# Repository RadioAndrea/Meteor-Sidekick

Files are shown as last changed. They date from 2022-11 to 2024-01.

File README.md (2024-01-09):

# Meteor-Sidekick
Slide out keyboard for modern smartphones

Uses Nice!Nano as a microcontroller and the first implementation is sized to a Pixel 7 Pro

Current implementation is with the Kailh Scissor switches as they are very thin and available unlike the ultramecs 6c switches.

If you know of a way to get thinner mechanical switches, like the Ultramecs, at a reasonable price (not $150 a board), please raise an issue in this repo.

# Project Status
## November 2022
Boards that were created were milled with the wrong size of drill bit due to board fab error.
Fabricator remade boards to rectify this.

## January 2023
New boards arrived and components are still being collected.

## Jul 2023
Solder paste stencil arrived and reflow oven was obtained.
Soldering of transistors will happen by paste and reflow, while switches will be done entirely by hand.

## Jan 2024
Board has been produced and now soldered thanks to my steady handed assistant.

# Images
## Real Photographs
### SMD Soldering
SMD parts reflow soldered

### Adding Switches and Caps
Swithches installed, caps being added
### Praise the manufacturing tolerances
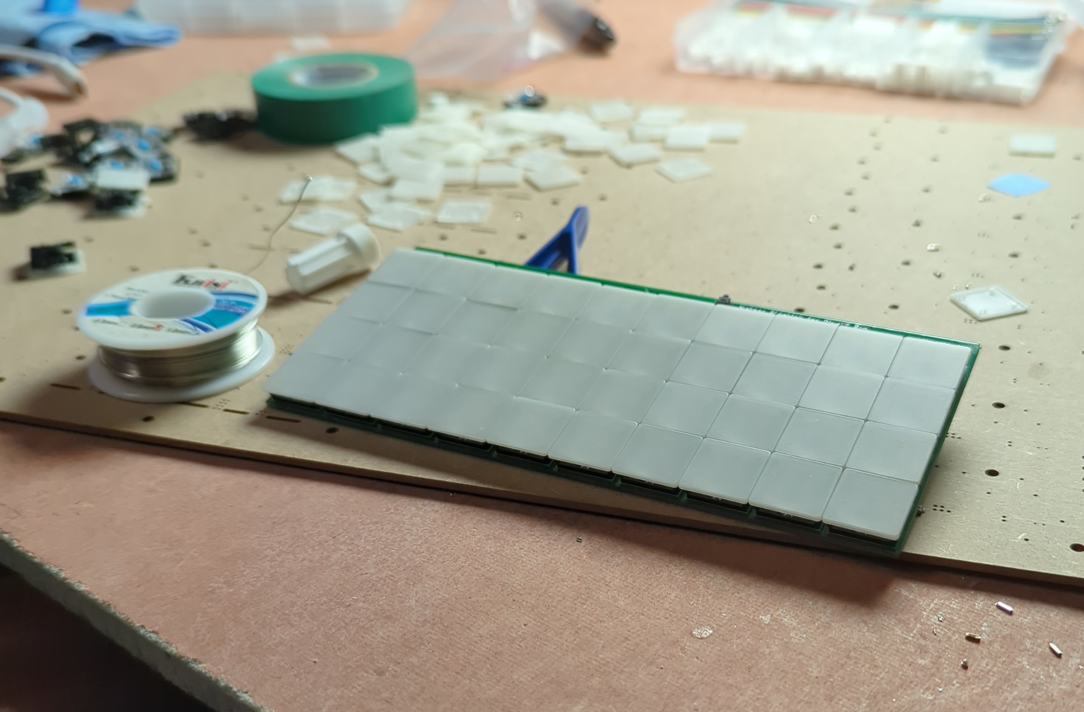
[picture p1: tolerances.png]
Only one keyswitch was out of tolerence


## 2D Drawing
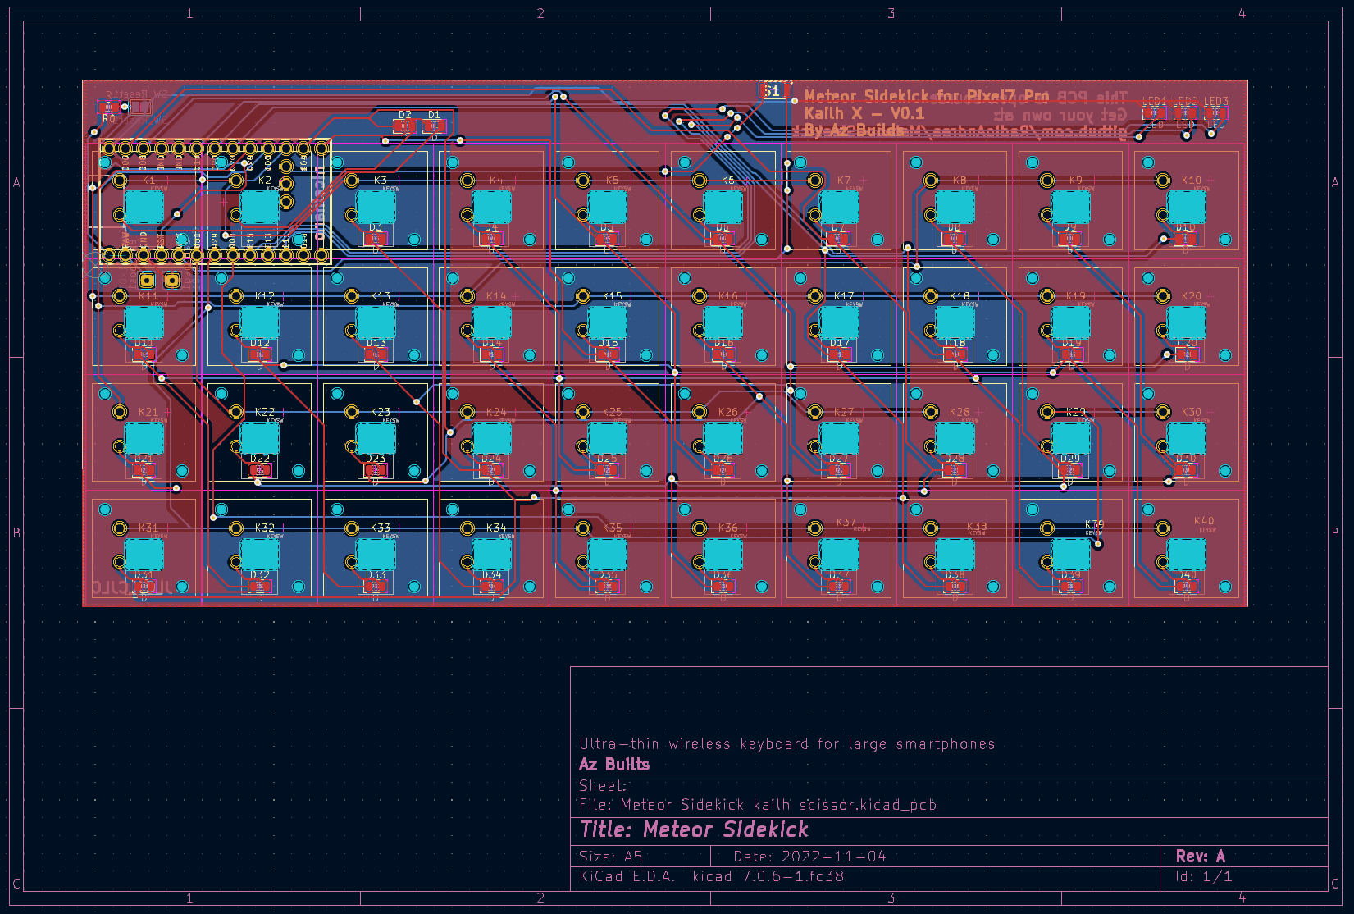
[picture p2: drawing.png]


## 3D Render
### Front

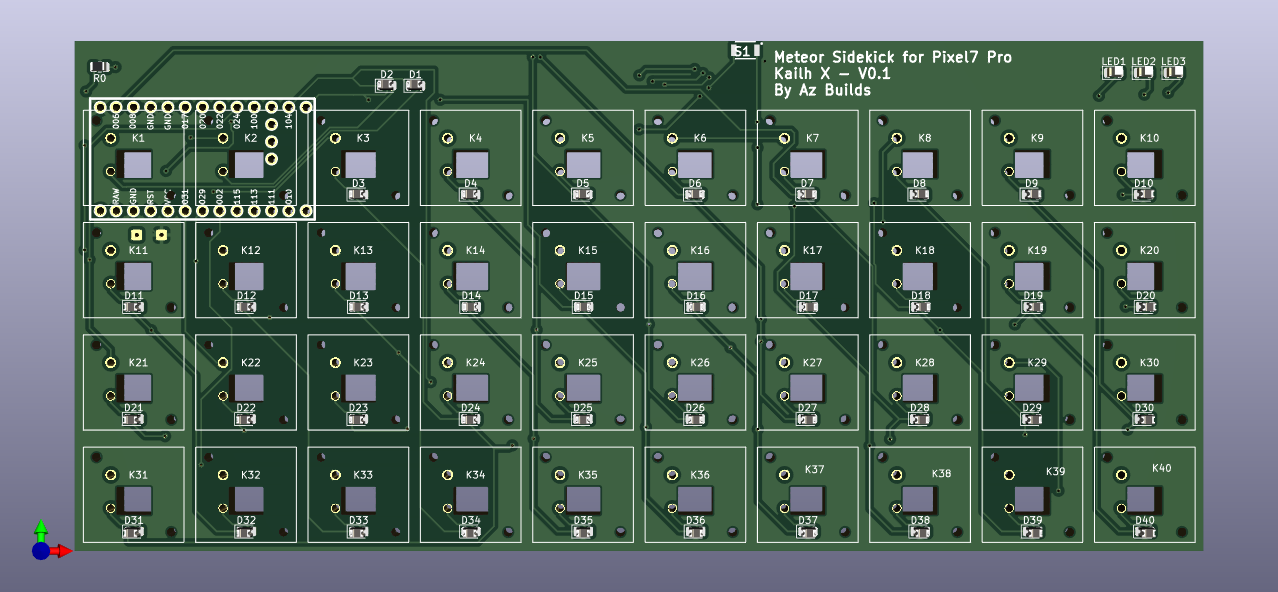
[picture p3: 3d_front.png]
Front of keyboard

### Back
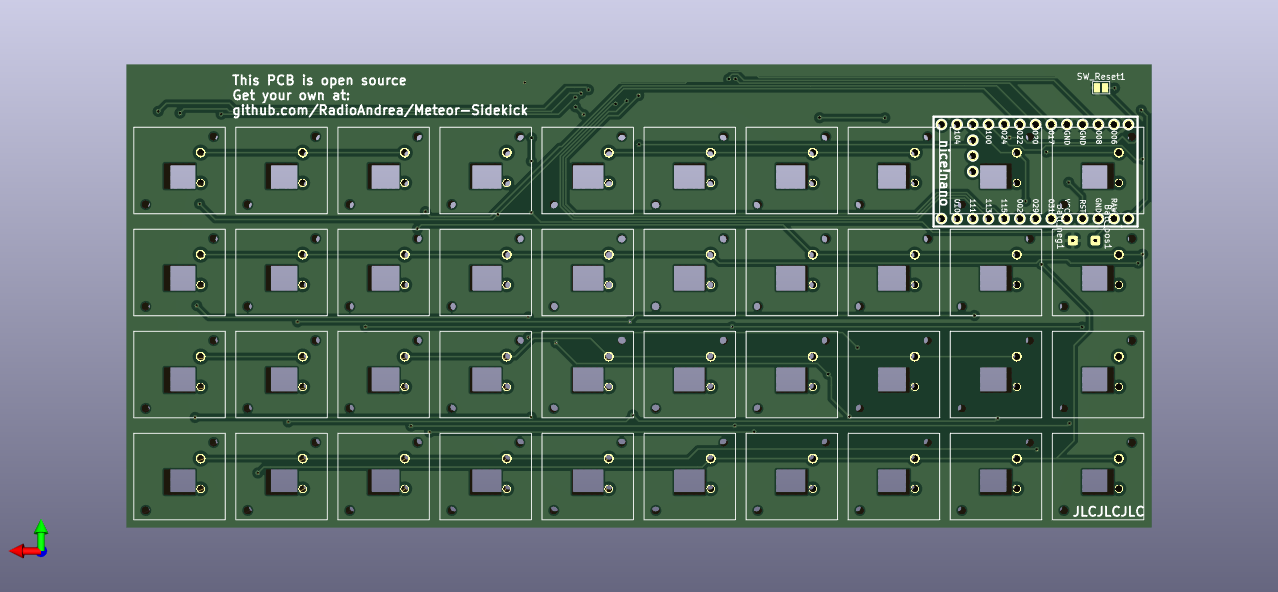
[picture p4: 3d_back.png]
Back of keyboard


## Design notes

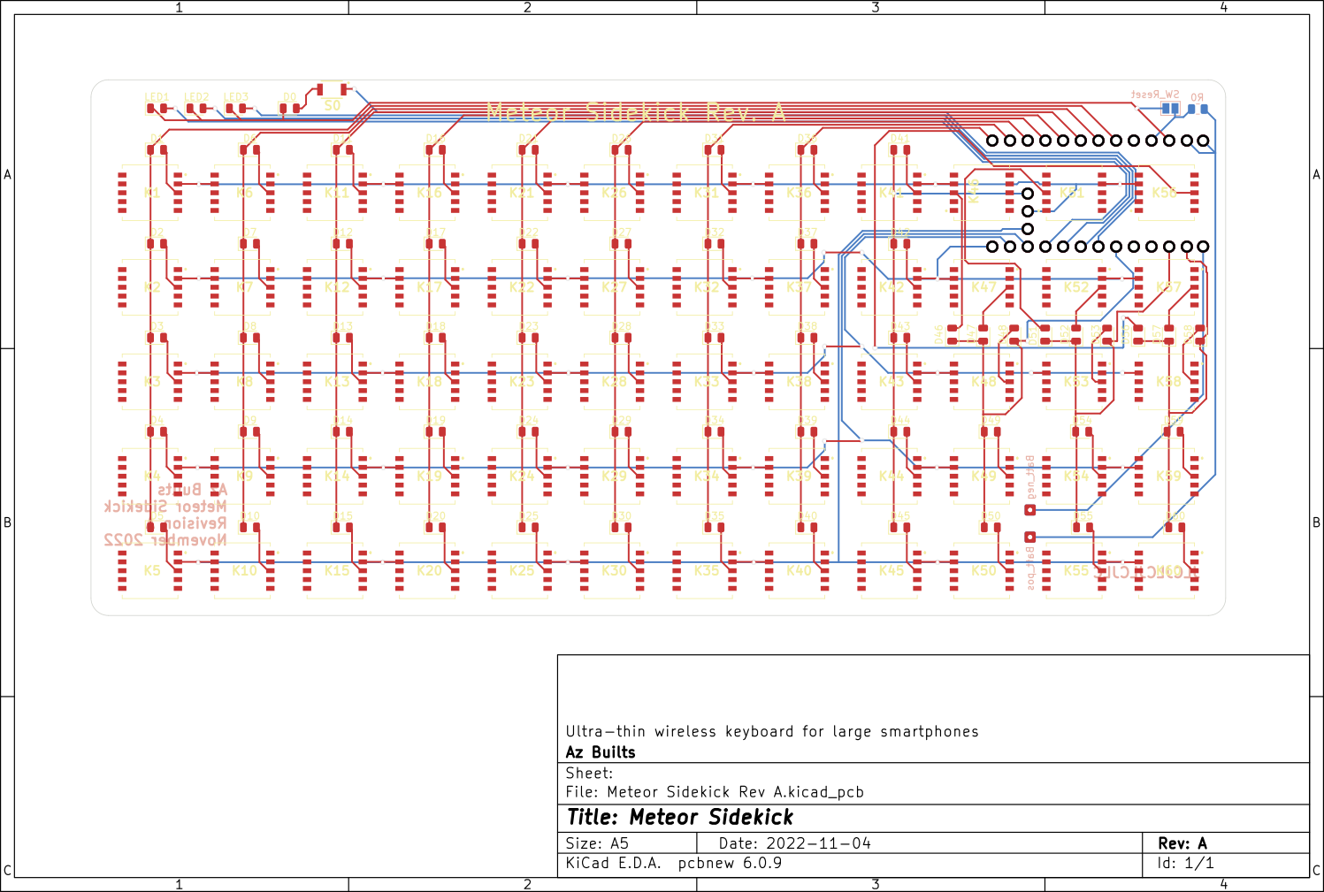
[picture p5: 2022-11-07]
ultramec-6/Meteor Sidekick Rev A.png

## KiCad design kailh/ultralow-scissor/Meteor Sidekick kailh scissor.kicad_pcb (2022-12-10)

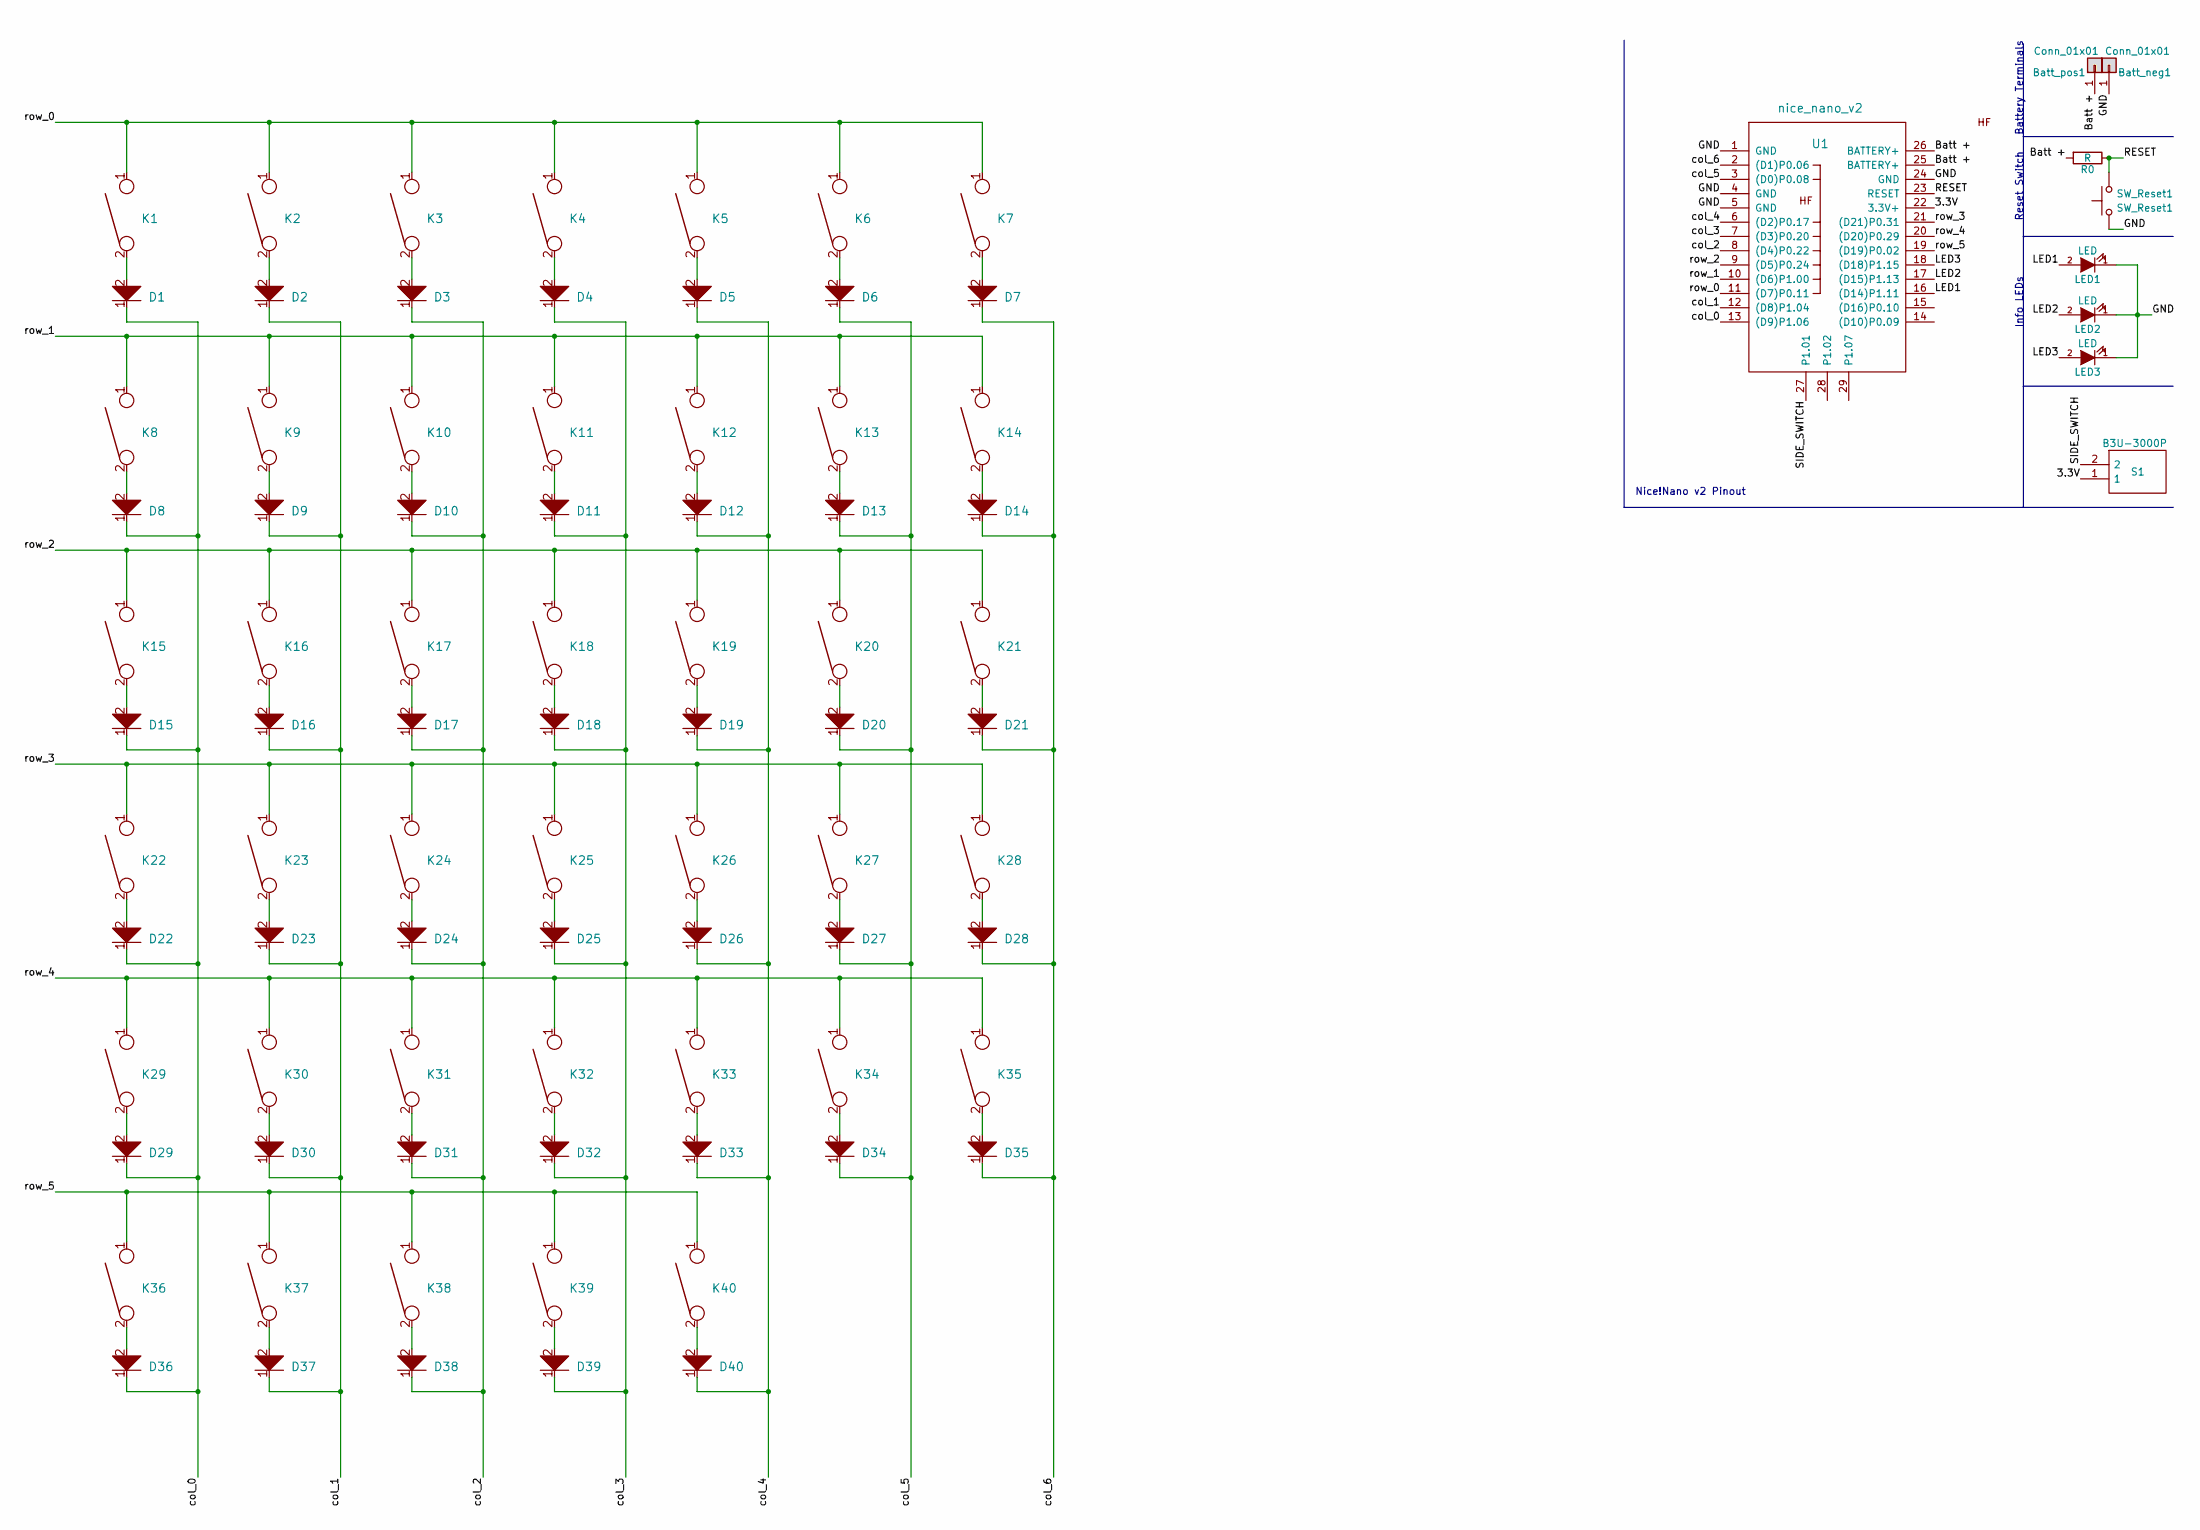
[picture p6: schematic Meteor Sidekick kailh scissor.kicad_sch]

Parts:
Batt_neg1: Conn_01x01; SolderWire-0.1sqmm_1x01_D0.4mm_OD1mm
Batt_pos1: Conn_01x01; SolderWire-0.1sqmm_1x01_D0.4mm_OD1mm
D1, D2, D3, D4, D5, D6, D7, D8, D9, D10, D11, D12, D13, D14, D15, D16, D17, D18, D19, D20, D21, D22, D23, D24, D25, D26, D27, D28, D29, D30, D31, D32, D33, D34, D35, D36, D37, D38, D39, D40: D; D_0805_2012Metric
K1, K2, K3, K4, K5, K6, K7, K8, K9, K10, K11, K12, K13, K14, K15, K16, K17, K18, K19, K20, K21, K22, K23, K24, K25, K26, K27, K28, K29, K30, K31, K32, K33, K34, K35, K36, K37, K38, K39, K40: KEYSW; Kailh-PG1425-X-Switch
LED1, LED2, LED3: LED; LED_0805_2012Metric
R0: R; R_0805_2012Metric
S1: B3U-3000P; B3U-1000P; Mouser Part Number 653-B3U-3000P
SW_Reset1: SW_Reset1; SolderJumper-2_P1.3mm_Open_Pad1.0x1.5mm
U1: nice_nano_v2

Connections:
/3.3V: S1.1, U1.22 (3.3V+)
/Batt +: Batt_pos1.1, R0.2, U1.25 (BATTERY+), U1.26 (BATTERY+)
/GND: Batt_neg1.1, LED1.1 (K), LED2.1 (K), LED3.1 (K), SW_Reset1.1, U1.1 (GND), U1.4 (GND), U1.5 (GND), U1.24 (GND)
/LED1: LED1.2 (A), U1.16 ((D14)P1.11)
/LED2: LED2.2 (A), U1.17 ((D15)P1.13)
/LED3: LED3.2 (A), U1.18 ((D18)P1.15)
/RESET: R0.1, SW_Reset1.2, U1.23 (RESET)
/SIDE_SWITCH: S1.2, U1.27 (P1.01)
/col_0: D1.1, D8.1, D15.1, D22.1, D29.1, D36.1, U1.13 ((D9)P1.06)
/col_1: D2.1, D9.1, D16.1, D23.1, D30.1, D37.1, U1.12 ((D8)P1.04)
/col_2: D3.1, D10.1, D17.1, D24.1, D31.1, D38.1, U1.8 ((D4)P0.22)
/col_3: D4.1, D11.1, D18.1, D25.1, D32.1, D39.1, U1.7 ((D3)P0.20)
/col_4: D5.1, D12.1, D19.1, D26.1, D33.1, D40.1, U1.6 ((D2)P0.17)
/col_5: D6.1, D13.1, D20.1, D27.1, D34.1, U1.3 ((D0)P0.08)
/col_6: D7.1, D14.1, D21.1, D28.1, D35.1, U1.2 ((D1)P0.06)
/row_0: K1.1, K2.1, K3.1, K4.1, K5.1, K6.1, K7.1, U1.11 ((D7)P0.11)
/row_1: K8.1, K9.1, K10.1, K11.1, K12.1, K13.1, K14.1, U1.10 ((D6)P1.00)
/row_2: K15.1, K16.1, K17.1, K18.1, K19.1, K20.1, K21.1, U1.9 ((D5)P0.24)
/row_3: K22.1, K23.1, K24.1, K25.1, K26.1, K27.1, K28.1, U1.21 ((D21)P0.31)
/row_4: K29.1, K30.1, K31.1, K32.1, K33.1, K34.1, K35.1, U1.20 ((D20)P0.29)
/row_5: K36.1, K37.1, K38.1, K39.1, K40.1, U1.19 ((D19)P0.02)
unnamed: D1.2, K1.2
unnamed: D2.2, K2.2
unnamed: D3.2, K3.2
unnamed: D4.2, K4.2
unnamed: D5.2, K5.2
unnamed: D6.2, K6.2
unnamed: D7.2, K7.2
unnamed: D8.2, K8.2
unnamed: D9.2, K9.2
unnamed: D10.2, K10.2
unnamed: D11.2, K11.2
unnamed: D12.2, K12.2
unnamed: D13.2, K13.2
unnamed: D14.2, K14.2
unnamed: D15.2, K15.2
unnamed: D16.2, K16.2
unnamed: D17.2, K17.2
unnamed: D18.2, K18.2
unnamed: D19.2, K19.2
unnamed: D20.2, K20.2
unnamed: D21.2, K21.2
unnamed: D22.2, K22.2
unnamed: D23.2, K23.2
unnamed: D24.2, K24.2
unnamed: D25.2, K25.2
unnamed: D26.2, K26.2
unnamed: D27.2, K27.2
unnamed: D28.2, K28.2
unnamed: D29.2, K29.2
unnamed: D30.2, K30.2
unnamed: D31.2, K31.2
unnamed: D32.2, K32.2
unnamed: D33.2, K33.2
unnamed: D34.2, K34.2
unnamed: D35.2, K35.2
unnamed: D36.2, K36.2
unnamed: D37.2, K37.2
unnamed: D38.2, K38.2
unnamed: D39.2, K39.2
unnamed: D40.2, K40.2

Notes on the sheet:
Nice!Nano v2 Pinout
Battery Terminals
Reset Switch
Info LEDs

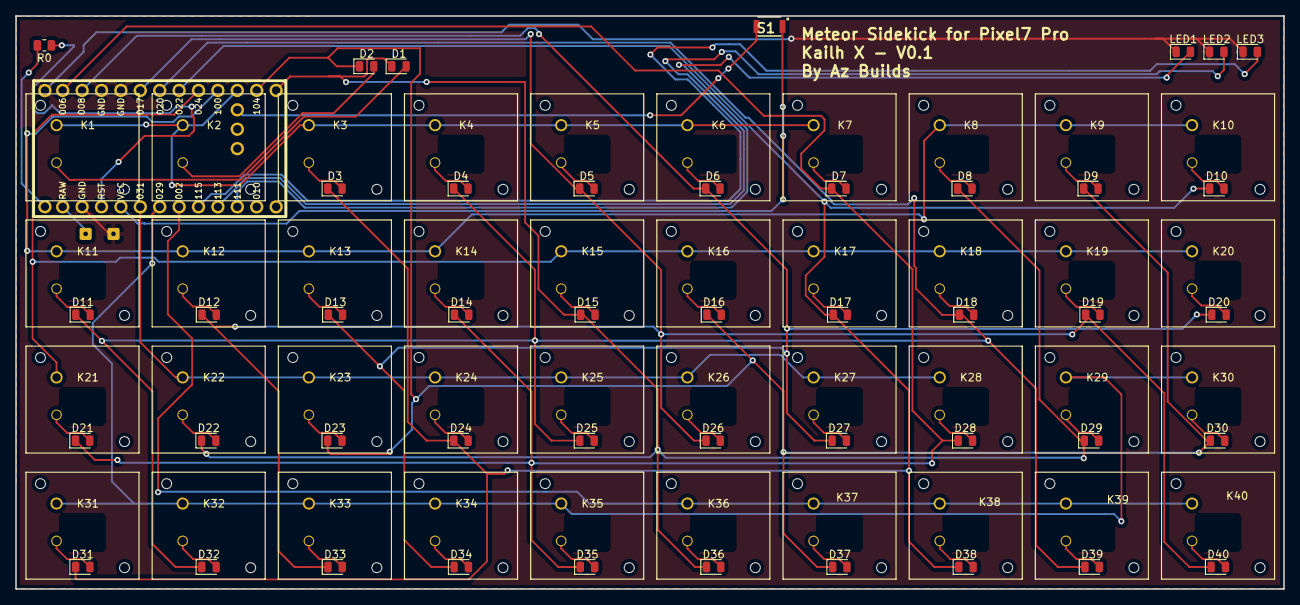
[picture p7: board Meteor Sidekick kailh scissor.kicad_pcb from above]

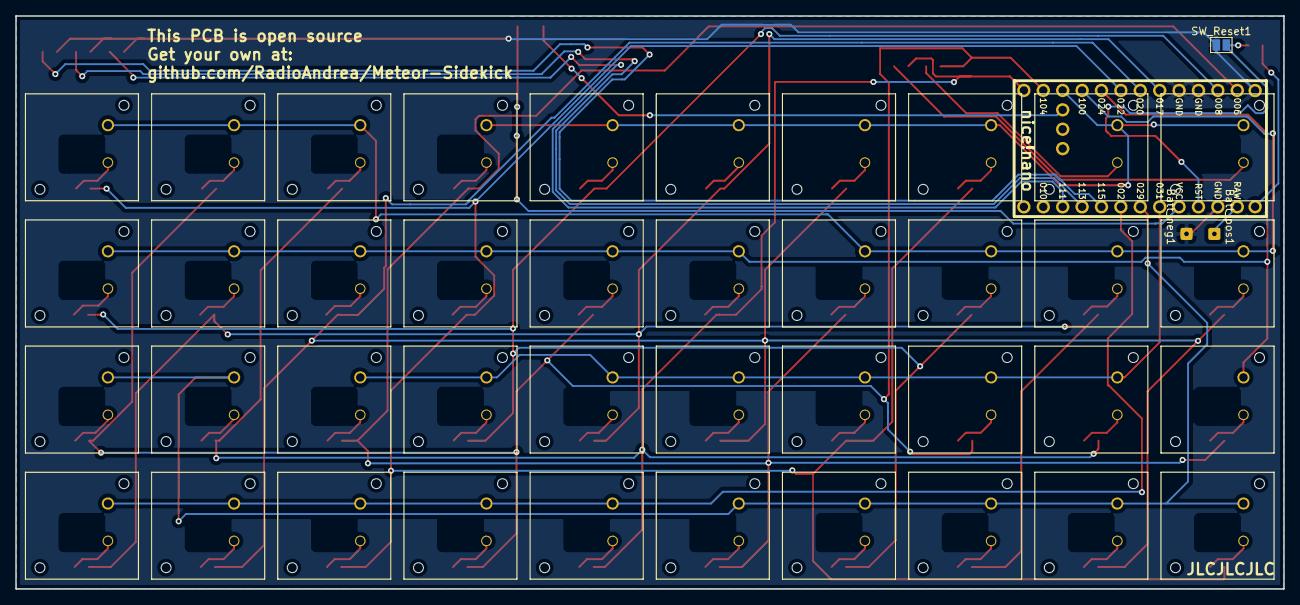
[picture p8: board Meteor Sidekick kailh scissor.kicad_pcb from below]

Board: 2 copper layers, 166.0 x 75.0 mm, 89 parts (4 on the bottom side), 61 nets.

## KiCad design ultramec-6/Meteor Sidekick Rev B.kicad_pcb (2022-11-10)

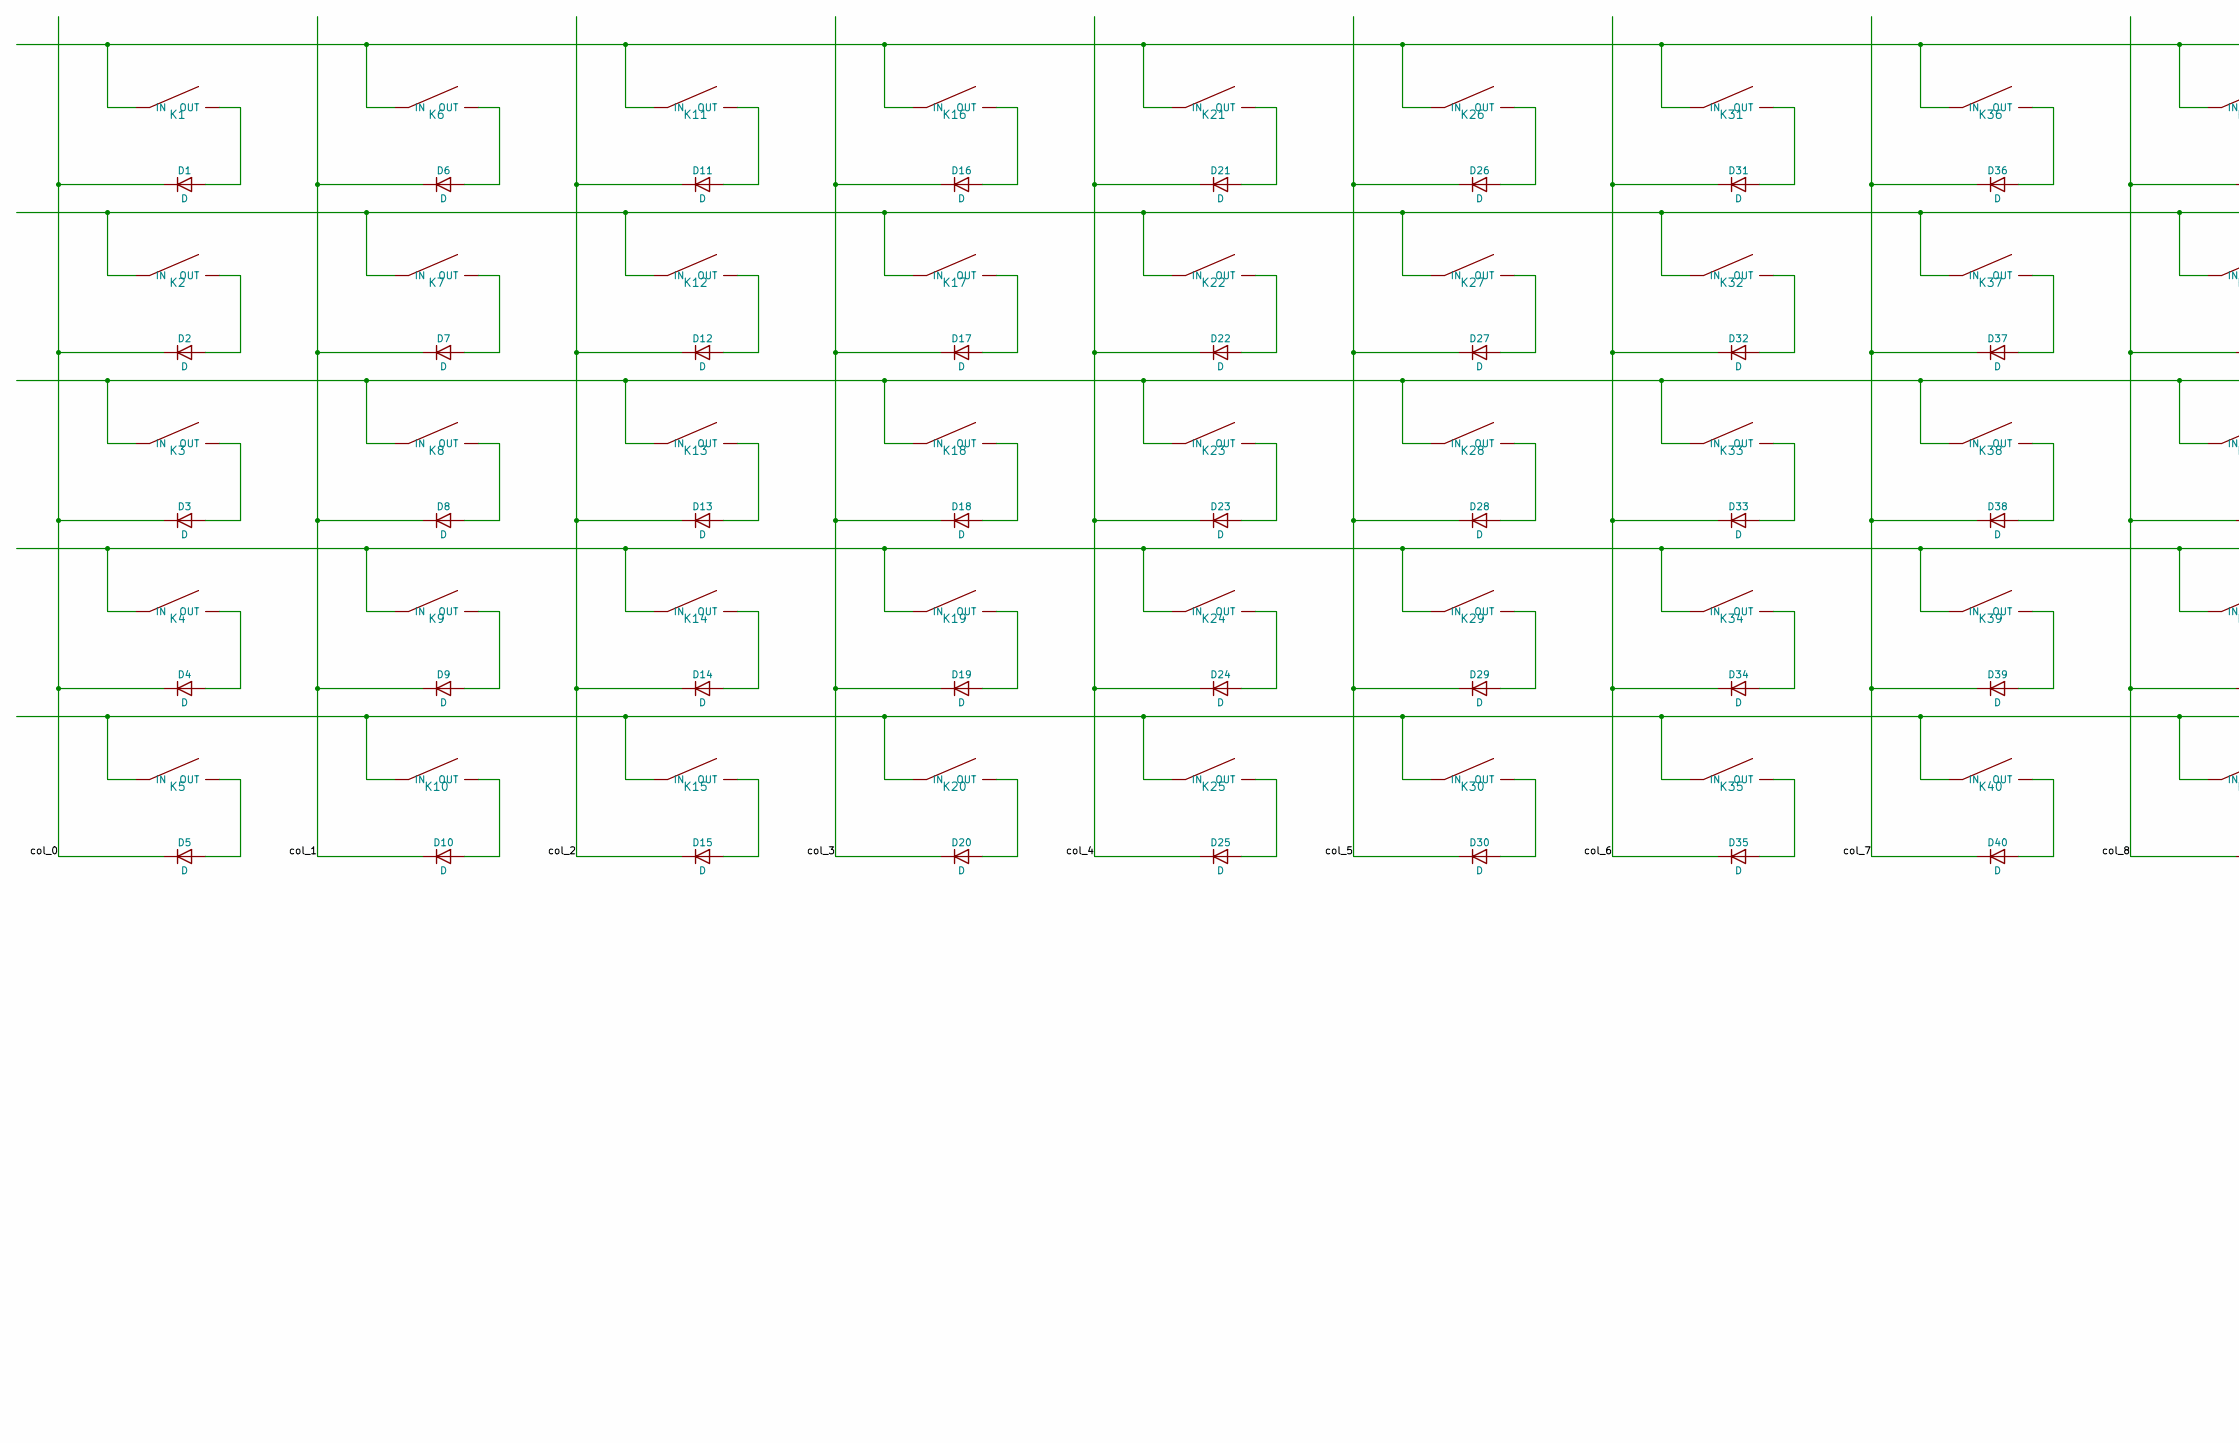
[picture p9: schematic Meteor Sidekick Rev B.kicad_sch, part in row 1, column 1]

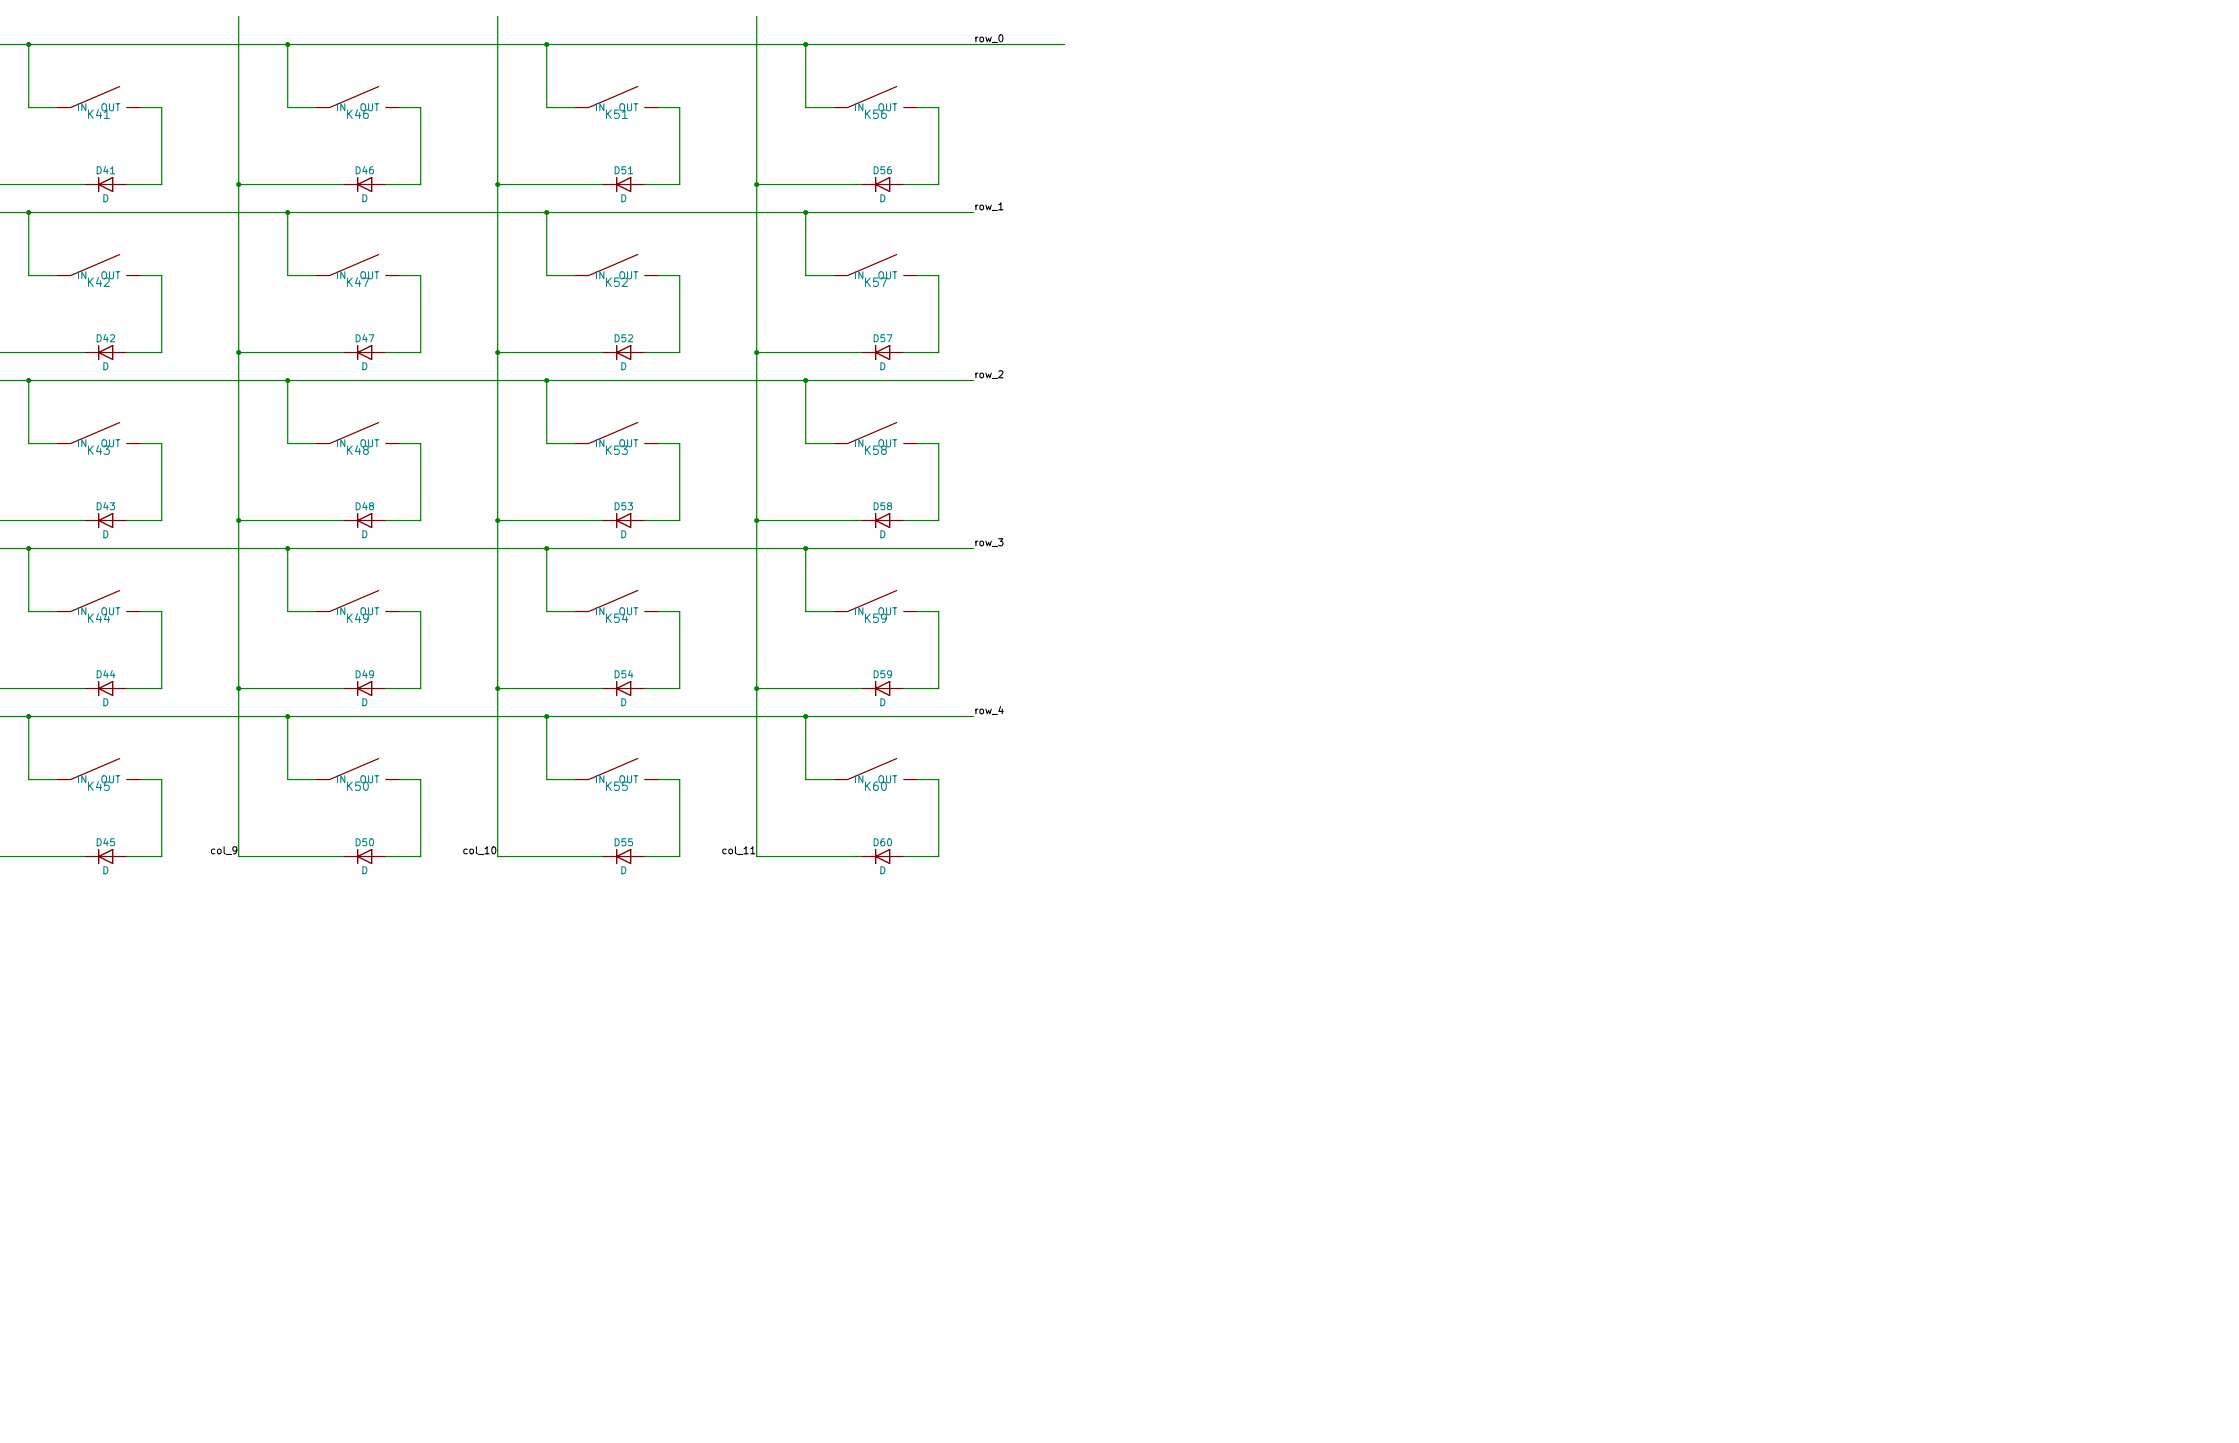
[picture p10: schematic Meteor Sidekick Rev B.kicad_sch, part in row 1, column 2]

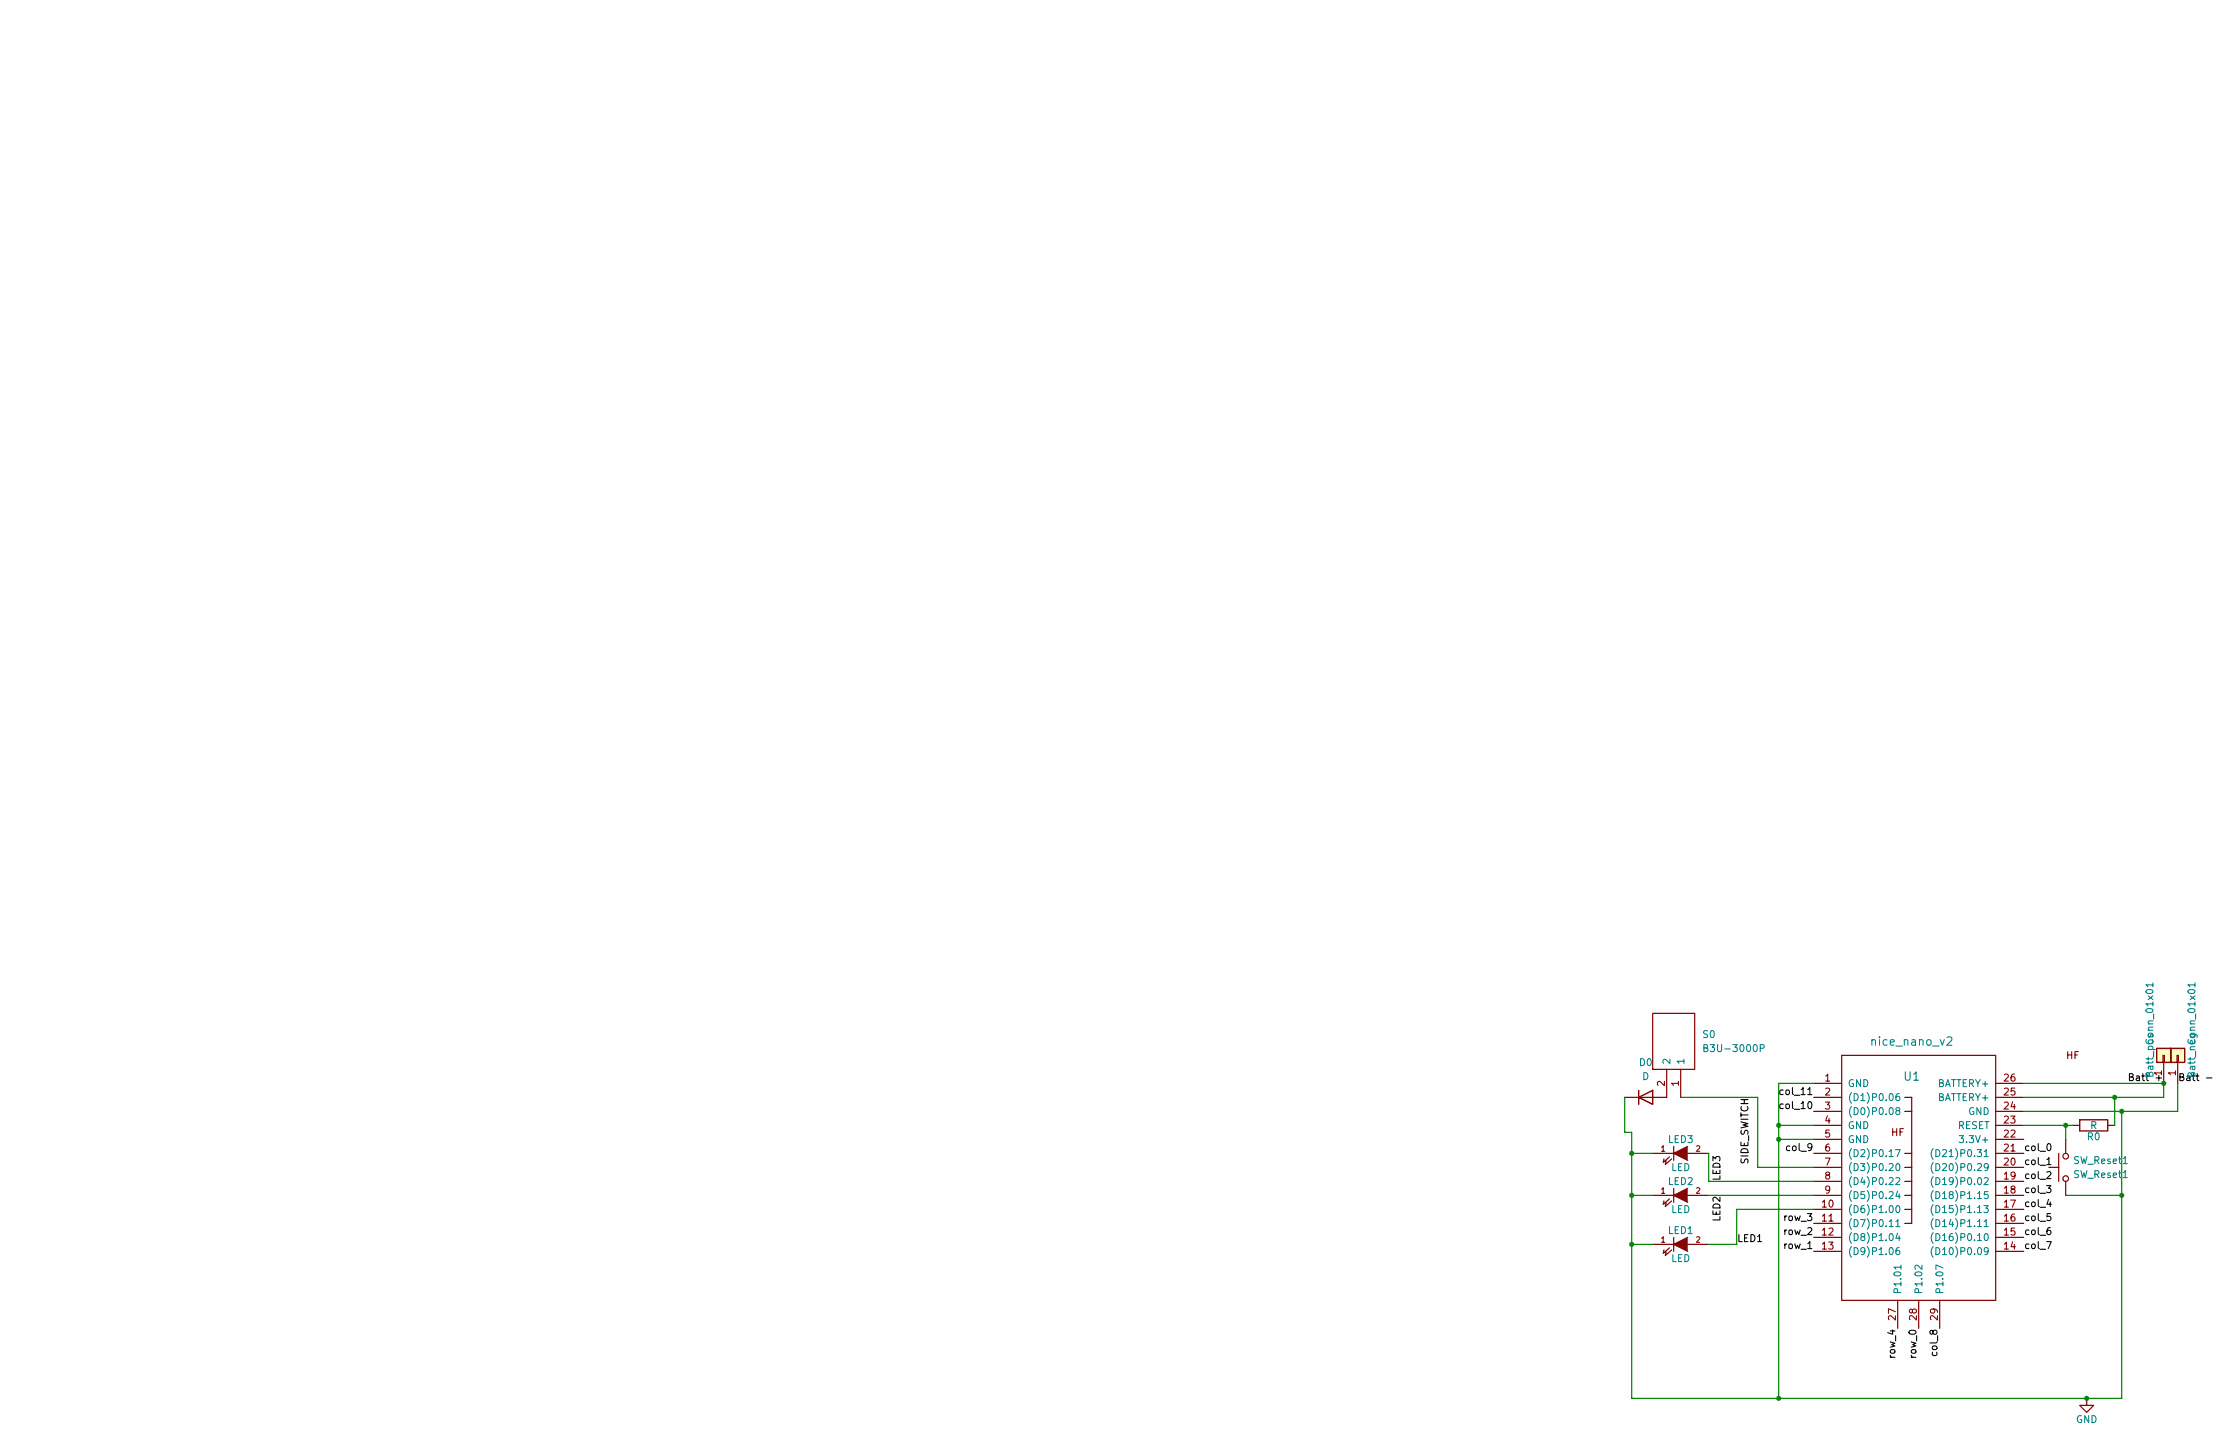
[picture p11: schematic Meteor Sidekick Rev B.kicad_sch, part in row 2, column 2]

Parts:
Batt_neg: Conn_01x01; SolderWire-0.1sqmm_1x01_D0.4mm_OD1mm
Batt_pos: Conn_01x01; SolderWire-0.1sqmm_1x01_D0.4mm_OD1mm
D0, D1, D2, D3, D4, D5, D6, D7, D8, D9, D10, D11, D12, D13, D14, D15, D16, D17, D18, D19, D20, D21, D22, D23, D24, D25, D26, D27, D28, D29, D30, D31, D32, D33, D34, D35, D36, D37, D38, D39, D40, D41, D42, D43, D44, D45, D46, D47, D48, D49, D50, D51, D52, D53, D54, D55, D56, D57, D58, D59, D60: D; D_0805_2012Metric
K1, K2, K3, K4, K5, K6, K7, K8, K9, K10, K11, K12, K13, K14, K15, K16, K17, K18, K19, K20, K21, K22, K23, K24, K25, K26, K27, K28, K29, K30, K31, K32, K33, K34, K35, K36, K37, K38, K39, K40, K41, K42, K43, K44, K45, K46, K47, K48, K49, K50, K51, K52, K53, K54, K55, K56, K57, K58, K59, K60: KEYSW_10; 6CJ1N0PR
LED1, LED2, LED3: LED; LED_0805_2012Metric
R0: R; R_0805_2012Metric
S0: B3U-3000P; B3U-1000P; Mouser Part Number 653-B3U-3000P
SW_Reset1: SW_Reset1; SolderJumper-2_P1.3mm_Open_Pad1.0x1.5mm
U1: nice_nano_v2

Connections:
/Batt +: Batt_pos.1, R0.1, U1.25 (BATTERY+), U1.26 (BATTERY+)
/LED1: LED1.2 (A), U1.10 ((D6)P1.00)
/LED2: LED2.2 (A), U1.9 ((D5)P0.24)
/LED3: LED3.2 (A), U1.8 ((D4)P0.22)
/SIDE_SWITCH: S0.1, U1.7 ((D3)P0.20)
/col_0: D1.1 (K), D2.1 (K), D3.1 (K), D4.1 (K), D5.1 (K), U1.21 ((D21)P0.31)
/col_1: D6.1 (K), D7.1 (K), D8.1 (K), D9.1 (K), D10.1 (K), U1.20 ((D20)P0.29)
/col_2: D11.1 (K), D12.1 (K), D13.1 (K), D14.1 (K), D15.1 (K), U1.19 ((D19)P0.02)
/col_3: D16.1 (K), D17.1 (K), D18.1 (K), D19.1 (K), D20.1 (K), U1.18 ((D18)P1.15)
/col_4: D21.1 (K), D22.1 (K), D23.1 (K), D24.1 (K), D25.1 (K), U1.17 ((D15)P1.13)
/col_5: D26.1 (K), D27.1 (K), D28.1 (K), D29.1 (K), D30.1 (K), U1.16 ((D14)P1.11)
/col_6: D31.1 (K), D32.1 (K), D33.1 (K), D34.1 (K), D35.1 (K), U1.15 ((D16)P0.10)
/col_7: D36.1 (K), D37.1 (K), D38.1 (K), D39.1 (K), D40.1 (K), U1.14 ((D10)P0.09)
/col_8: D41.1 (K), D42.1 (K), D43.1 (K), D44.1 (K), D45.1 (K), U1.29 (P1.07)
/col_9: D46.1 (K), D47.1 (K), D48.1 (K), D49.1 (K), D50.1 (K), U1.6 ((D2)P0.17)
/col_10: D51.1 (K), D52.1 (K), D53.1 (K), D54.1 (K), D55.1 (K), U1.3 ((D0)P0.08)
/col_11: D56.1 (K), D57.1 (K), D58.1 (K), D59.1 (K), D60.1 (K), U1.2 ((D1)P0.06)
/row_0: K1.3 (IN), K1.4 (IN), K1.7 (IN), K1.8 (IN), K6.3 (IN), K6.4 (IN), K6.7 (IN), K6.8 (IN), K11.3 (IN), K11.4 (IN), K11.7 (IN), K11.8 (IN), K16.3 (IN), K16.4 (IN), K16.7 (IN), K16.8 (IN), K21.3 (IN), K21.4 (IN), K21.7 (IN), K21.8 (IN), K26.3 (IN), K26.4 (IN), K26.7 (IN), K26.8 (IN), K31.3 (IN), K31.4 (IN), K31.7 (IN), K31.8 (IN), K36.3 (IN), K36.4 (IN), K36.7 (IN), K36.8 (IN), K41.3 (IN), K41.4 (IN), K41.7 (IN), K41.8 (IN), K46.3 (IN), K46.4 (IN), K46.7 (IN), K46.8 (IN), K51.3 (IN), K51.4 (IN), K51.7 (IN), K51.8 (IN), K56.3 (IN), K56.4 (IN), K56.7 (IN), K56.8 (IN), U1.28 (P1.02)
/row_1: K2.3 (IN), K2.4 (IN), K2.7 (IN), K2.8 (IN), K7.3 (IN), K7.4 (IN), K7.7 (IN), K7.8 (IN), K12.3 (IN), K12.4 (IN), K12.7 (IN), K12.8 (IN), K17.3 (IN), K17.4 (IN), K17.7 (IN), K17.8 (IN), K22.3 (IN), K22.4 (IN), K22.7 (IN), K22.8 (IN), K27.3 (IN), K27.4 (IN), K27.7 (IN), K27.8 (IN), K32.3 (IN), K32.4 (IN), K32.7 (IN), K32.8 (IN), K37.3 (IN), K37.4 (IN), K37.7 (IN), K37.8 (IN), K42.3 (IN), K42.4 (IN), K42.7 (IN), K42.8 (IN), K47.3 (IN), K47.4 (IN), K47.7 (IN), K47.8 (IN), K52.3 (IN), K52.4 (IN), K52.7 (IN), K52.8 (IN), K57.3 (IN), K57.4 (IN), K57.7 (IN), K57.8 (IN), U1.13 ((D9)P1.06)
/row_2: K3.3 (IN), K3.4 (IN), K3.7 (IN), K3.8 (IN), K8.3 (IN), K8.4 (IN), K8.7 (IN), K8.8 (IN), K13.3 (IN), K13.4 (IN), K13.7 (IN), K13.8 (IN), K18.3 (IN), K18.4 (IN), K18.7 (IN), K18.8 (IN), K23.3 (IN), K23.4 (IN), K23.7 (IN), K23.8 (IN), K28.3 (IN), K28.4 (IN), K28.7 (IN), K28.8 (IN), K33.3 (IN), K33.4 (IN), K33.7 (IN), K33.8 (IN), K38.3 (IN), K38.4 (IN), K38.7 (IN), K38.8 (IN), K43.3 (IN), K43.4 (IN), K43.7 (IN), K43.8 (IN), K48.3 (IN), K48.4 (IN), K48.7 (IN), K48.8 (IN), K53.3 (IN), K53.4 (IN), K53.7 (IN), K53.8 (IN), K58.3 (IN), K58.4 (IN), K58.7 (IN), K58.8 (IN), U1.12 ((D8)P1.04)
/row_3: K4.3 (IN), K4.4 (IN), K4.7 (IN), K4.8 (IN), K9.3 (IN), K9.4 (IN), K9.7 (IN), K9.8 (IN), K14.3 (IN), K14.4 (IN), K14.7 (IN), K14.8 (IN), K19.3 (IN), K19.4 (IN), K19.7 (IN), K19.8 (IN), K24.3 (IN), K24.4 (IN), K24.7 (IN), K24.8 (IN), K29.3 (IN), K29.4 (IN), K29.7 (IN), K29.8 (IN), K34.3 (IN), K34.4 (IN), K34.7 (IN), K34.8 (IN), K39.3 (IN), K39.4 (IN), K39.7 (IN), K39.8 (IN), K44.3 (IN), K44.4 (IN), K44.7 (IN), K44.8 (IN), K49.3 (IN), K49.4 (IN), K49.7 (IN), K49.8 (IN), K54.3 (IN), K54.4 (IN), K54.7 (IN), K54.8 (IN), K59.3 (IN), K59.4 (IN), K59.7 (IN), K59.8 (IN), U1.11 ((D7)P0.11)
/row_4: K5.3 (IN), K5.4 (IN), K5.7 (IN), K5.8 (IN), K10.3 (IN), K10.4 (IN), K10.7 (IN), K10.8 (IN), K15.3 (IN), K15.4 (IN), K15.7 (IN), K15.8 (IN), K20.3 (IN), K20.4 (IN), K20.7 (IN), K20.8 (IN), K25.3 (IN), K25.4 (IN), K25.7 (IN), K25.8 (IN), K30.3 (IN), K30.4 (IN), K30.7 (IN), K30.8 (IN), K35.3 (IN), K35.4 (IN), K35.7 (IN), K35.8 (IN), K40.3 (IN), K40.4 (IN), K40.7 (IN), K40.8 (IN), K45.3 (IN), K45.4 (IN), K45.7 (IN), K45.8 (IN), K50.3 (IN), K50.4 (IN), K50.7 (IN), K50.8 (IN), K55.3 (IN), K55.4 (IN), K55.7 (IN), K55.8 (IN), K60.3 (IN), K60.4 (IN), K60.7 (IN), K60.8 (IN), U1.27 (P1.01)
GND: Batt_neg.1, D0.1 (K), LED1.1 (K), LED2.1 (K), LED3.1 (K), SW_Reset1.1, U1.1 (GND), U1.4 (GND), U1.5 (GND), U1.24 (GND); also elsewhere on the board
unnamed: D0.2 (A), S0.2
unnamed: D1.2 (A), K1.5 (OUT), K1.6 (OUT)
unnamed: D2.2 (A), K2.5 (OUT), K2.6 (OUT)
unnamed: D3.2 (A), K3.5 (OUT), K3.6 (OUT)
unnamed: D4.2 (A), K4.5 (OUT), K4.6 (OUT)
unnamed: D5.2 (A), K5.5 (OUT), K5.6 (OUT)
unnamed: D6.2 (A), K6.5 (OUT), K6.6 (OUT)
unnamed: D7.2 (A), K7.5 (OUT), K7.6 (OUT)
unnamed: D8.2 (A), K8.5 (OUT), K8.6 (OUT)
unnamed: D9.2 (A), K9.5 (OUT), K9.6 (OUT)
unnamed: D10.2 (A), K10.5 (OUT), K10.6 (OUT)
unnamed: D11.2 (A), K11.5 (OUT), K11.6 (OUT)
unnamed: D12.2 (A), K12.5 (OUT), K12.6 (OUT)
unnamed: D13.2 (A), K13.5 (OUT), K13.6 (OUT)
unnamed: D14.2 (A), K14.5 (OUT), K14.6 (OUT)
unnamed: D15.2 (A), K15.5 (OUT), K15.6 (OUT)
unnamed: D16.2 (A), K16.5 (OUT), K16.6 (OUT)
unnamed: D17.2 (A), K17.5 (OUT), K17.6 (OUT)
unnamed: D18.2 (A), K18.5 (OUT), K18.6 (OUT)
unnamed: D19.2 (A), K19.5 (OUT), K19.6 (OUT)
unnamed: D20.2 (A), K20.5 (OUT), K20.6 (OUT)
unnamed: D21.2 (A), K21.5 (OUT), K21.6 (OUT)
unnamed: D22.2 (A), K22.5 (OUT), K22.6 (OUT)
unnamed: D23.2 (A), K23.5 (OUT), K23.6 (OUT)
unnamed: D24.2 (A), K24.5 (OUT), K24.6 (OUT)
unnamed: D25.2 (A), K25.5 (OUT), K25.6 (OUT)
unnamed: D26.2 (A), K26.5 (OUT), K26.6 (OUT)
unnamed: D27.2 (A), K27.5 (OUT), K27.6 (OUT)
unnamed: D28.2 (A), K28.5 (OUT), K28.6 (OUT)
unnamed: D29.2 (A), K29.5 (OUT), K29.6 (OUT)
unnamed: D30.2 (A), K30.5 (OUT), K30.6 (OUT)
unnamed: D31.2 (A), K31.5 (OUT), K31.6 (OUT)
unnamed: D32.2 (A), K32.5 (OUT), K32.6 (OUT)
unnamed: D33.2 (A), K33.5 (OUT), K33.6 (OUT)
unnamed: D34.2 (A), K34.5 (OUT), K34.6 (OUT)
unnamed: D35.2 (A), K35.5 (OUT), K35.6 (OUT)
unnamed: D36.2 (A), K36.5 (OUT), K36.6 (OUT)
unnamed: D37.2 (A), K37.5 (OUT), K37.6 (OUT)
unnamed: D38.2 (A), K38.5 (OUT), K38.6 (OUT)
unnamed: D39.2 (A), K39.5 (OUT), K39.6 (OUT)
unnamed: D40.2 (A), K40.5 (OUT), K40.6 (OUT)
unnamed: D41.2 (A), K41.5 (OUT), K41.6 (OUT)
unnamed: D42.2 (A), K42.5 (OUT), K42.6 (OUT)
unnamed: D43.2 (A), K43.5 (OUT), K43.6 (OUT)
unnamed: D44.2 (A), K44.5 (OUT), K44.6 (OUT)
unnamed: D45.2 (A), K45.5 (OUT), K45.6 (OUT)
unnamed: D46.2 (A), K46.5 (OUT), K46.6 (OUT)
unnamed: D47.2 (A), K47.5 (OUT), K47.6 (OUT)
unnamed: D48.2 (A), K48.5 (OUT), K48.6 (OUT)
unnamed: D49.2 (A), K49.5 (OUT), K49.6 (OUT)
unnamed: D50.2 (A), K50.5 (OUT), K50.6 (OUT)
unnamed: D51.2 (A), K51.5 (OUT), K51.6 (OUT)
unnamed: D52.2 (A), K52.5 (OUT), K52.6 (OUT)
unnamed: D53.2 (A), K53.5 (OUT), K53.6 (OUT)
unnamed: D54.2 (A), K54.5 (OUT), K54.6 (OUT)
unnamed: D55.2 (A), K55.5 (OUT), K55.6 (OUT)
unnamed: D56.2 (A), K56.5 (OUT), K56.6 (OUT)
unnamed: D57.2 (A), K57.5 (OUT), K57.6 (OUT)
unnamed: D58.2 (A), K58.5 (OUT), K58.6 (OUT)
unnamed: D59.2 (A), K59.5 (OUT), K59.6 (OUT)
unnamed: D60.2 (A), K60.5 (OUT), K60.6 (OUT)
unnamed 84: R0.2, SW_Reset1.2, U1.23 (RESET); also elsewhere on the board

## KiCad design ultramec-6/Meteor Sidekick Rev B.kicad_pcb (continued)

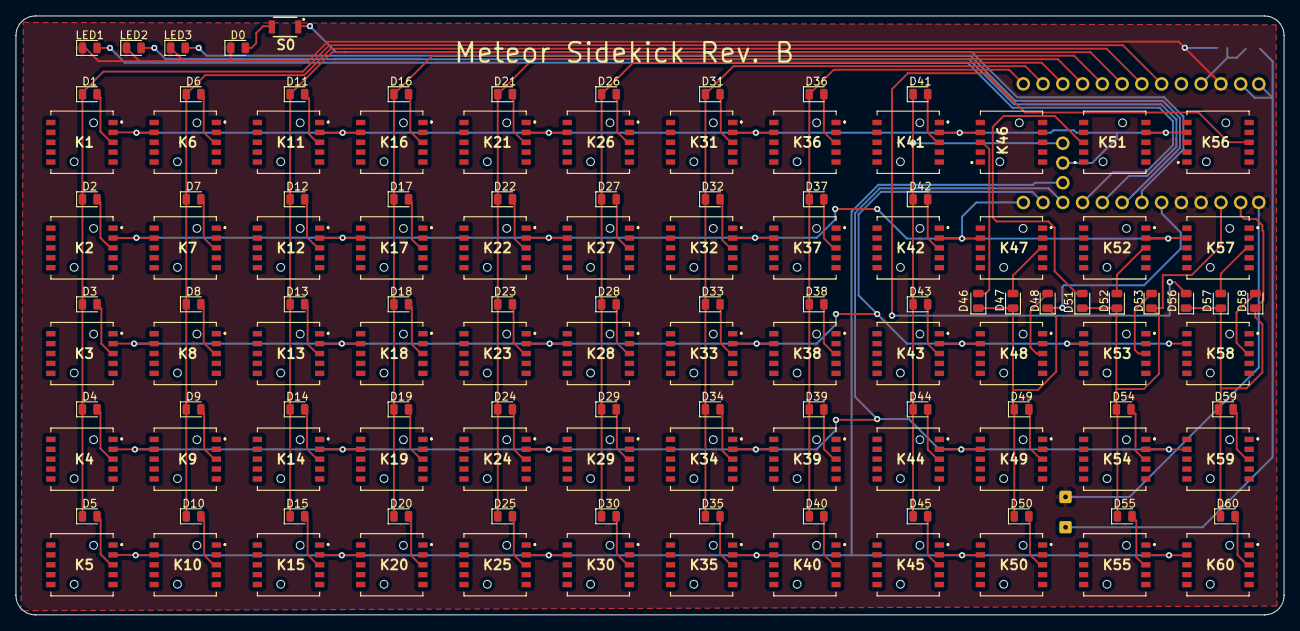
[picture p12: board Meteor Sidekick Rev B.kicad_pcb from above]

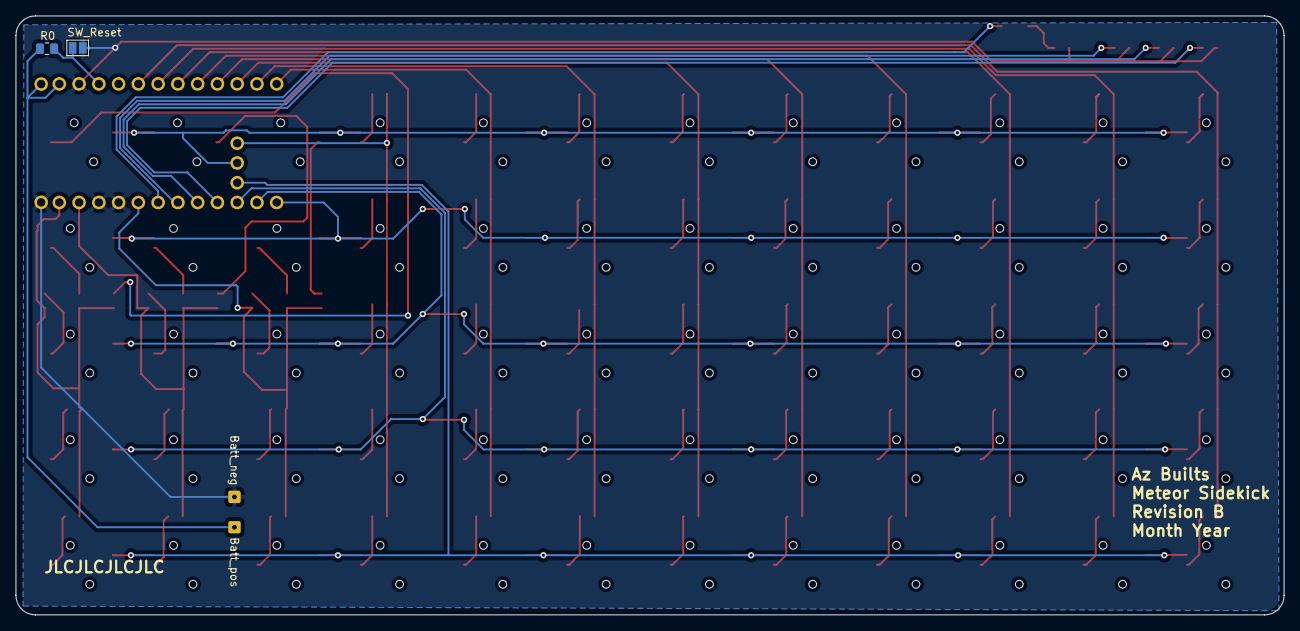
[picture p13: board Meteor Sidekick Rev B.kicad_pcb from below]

Board: 2 copper layers, 163.0 x 77.0 mm, 130 parts (5 on the bottom side), 85 nets.

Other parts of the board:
SW_Reset: SW_Reset; SolderJumper-2_P1.3mm_Open_Pad1.0x1.5mm

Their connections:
GND: SW_Reset.1; also elsewhere on the board
unnamed 84: SW_Reset.2; also elsewhere on the board

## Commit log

2022-11-07 Initial Commit
    Adds Rev A board
    [Meteor Sidekick B.kicad_pcb, Meteor Sidekick B.kicad_sch, Meteor Sidekick Rev A.kicad_pcb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]
2022-11-10 Rev B initial - ground plane
    Added ground plane to both sides of the board
    [Meteor Sidekick B.kicad_pcb, Meteor Sidekick Rev B.kicad_pcb, Meteor Sidekick Rev B.kicad_sch]
2022-11-24 Added initial kailh designs
    Added a design for kailh chocos and x scissors
    [Meteor Sidekick Rev A.kicad_pcb, Meteor Sidekick Rev A.kicad_sch, Meteor Sidekick Rev B.kicad_pcb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]
2022-11-24 Fixed reset and batt on isolated gnd
    [Meteor Sidekick kailh scissor.kicad_pcb]
2022-12-10 Fixed missed connections
    Reset now connected
    LEDs now connected
    [Meteor Sidekick kailh scissor.kicad_pcb]
2022-12-10 Created board cut files
    [Meteor Sidekick kailh scissor.kicad_pcb]
